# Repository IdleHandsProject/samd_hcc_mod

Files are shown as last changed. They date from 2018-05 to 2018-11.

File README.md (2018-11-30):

# SAMD21 HCC Module

Check out the Kickstarter for the HCC Module!

[HCC Mod Kickstarter](https://www.kickstarter.com/projects/idlehandsdev/hcc-mod-ready-to-solder-arduino-module)

An easy to solder Arduino and CircuitPython compatible surface mount module aimed to bridge the gap between using "off the shelf" microcontrollers to creating custom PCBs. 
The module will come with a standard USB enabled Arduino bootloader.

## Arduino IDE Install

Inside of the folder "BOOTLOADER" there is a folder called "IdleHandsDev". Once you download or clone the repo, take the IdleHandsDev folder and place it in the "hardware" folder found within your default Arduino folder. This will allow you to select the HCC Module in the Arduino IDE. You can also use "Arduino/Genuino Zero (Native USB). It will have the same pinout.

## Videos

Kickstarter Vid (https://youtu.be/BM-LiPFgZBc)

Build Vid (https://youtu.be/7S2FcrVHBxY)

## Demo Boards

### Cherry MX Board

Cherry MX Demo (https://youtu.be/bd1iaVNwYvI)

### MOD_BOY - Arduino Gaming Device and Gaming Controller

MOD BOY (https://youtu.be/LRTtZSRfYVY)

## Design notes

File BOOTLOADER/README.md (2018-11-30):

* Transfer "IdleHandsDev" folder into your Arduino/hardware folder to view the "HCC Module" board. Otherwise use either "Arduino Zero (Native USB)" or "Sparkfun SAMD Breakout Board" *

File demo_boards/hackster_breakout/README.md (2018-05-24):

# SAMD21 Bridge Module
An easy to solder Arduino compatible surface mount module aimed to bridge the gap between using "off the shelf" microcontrollers to creating custom PCBs.

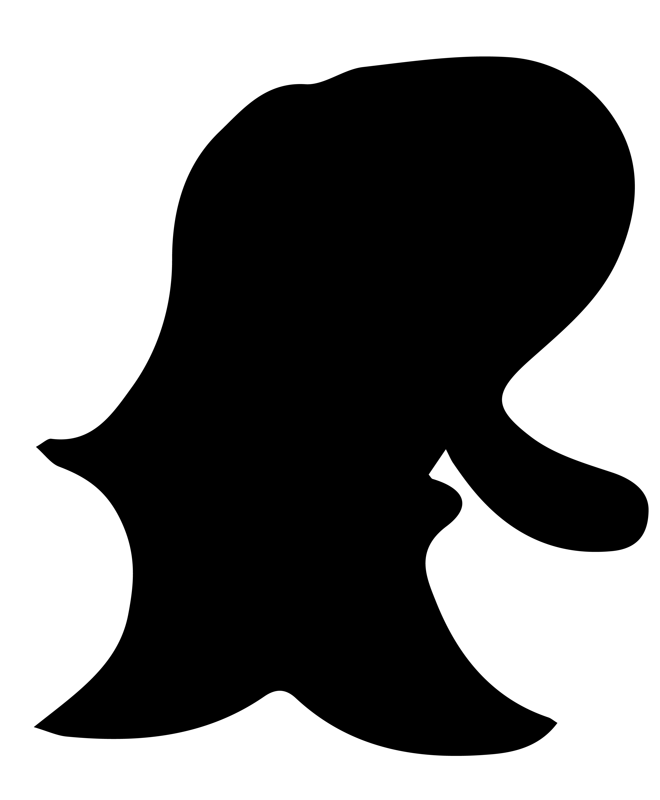
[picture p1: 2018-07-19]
demo_boards/programmer_hcc/images/1600ppi/Asset 3.png

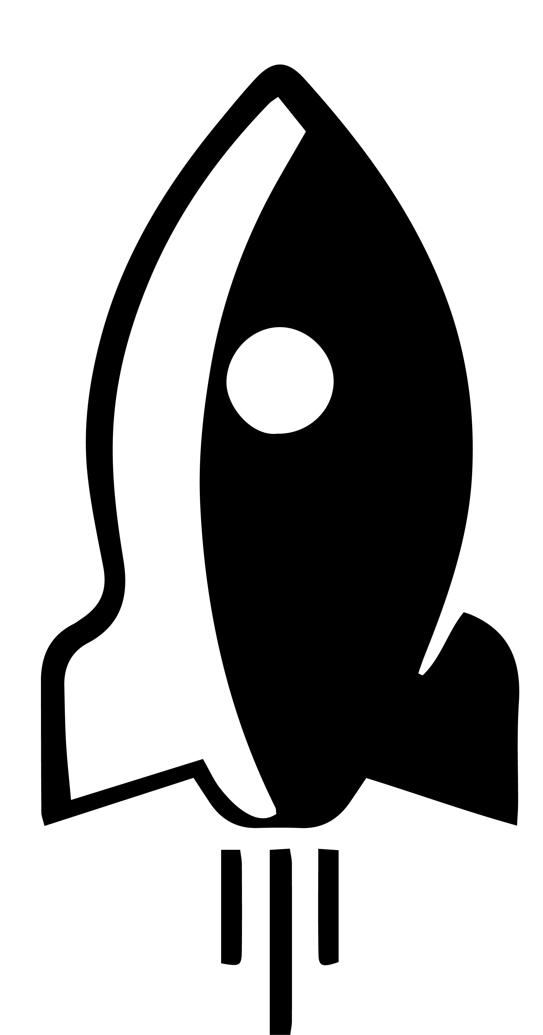
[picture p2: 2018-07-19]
demo_boards/hcc_boy/images/1600ppi/Asset 1.png

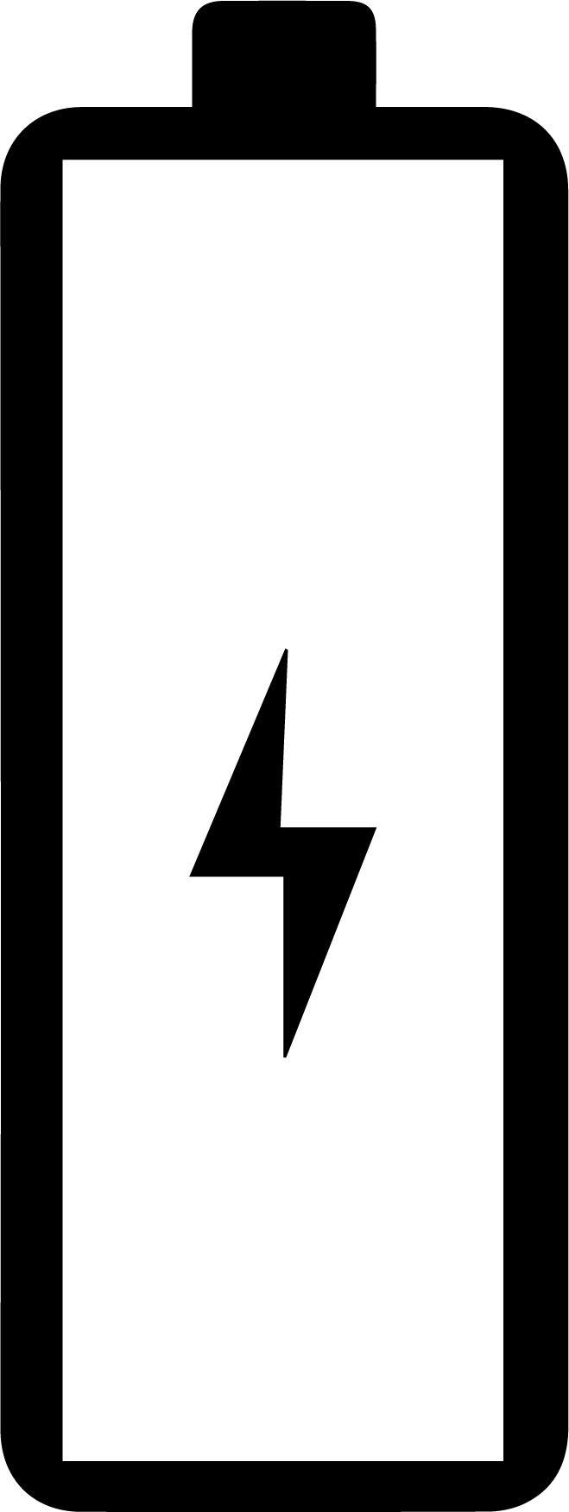
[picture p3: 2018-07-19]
demo_boards/hcc_boy/images/300ppi/Asset 1.png

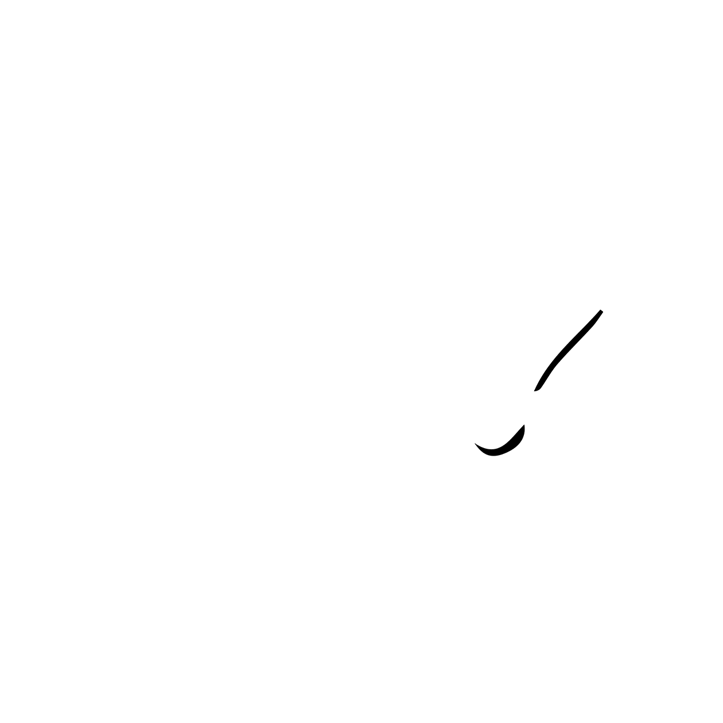
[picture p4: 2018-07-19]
demo_boards/programmer_hcc/images/BOOTCOMMANDER_MASK.png

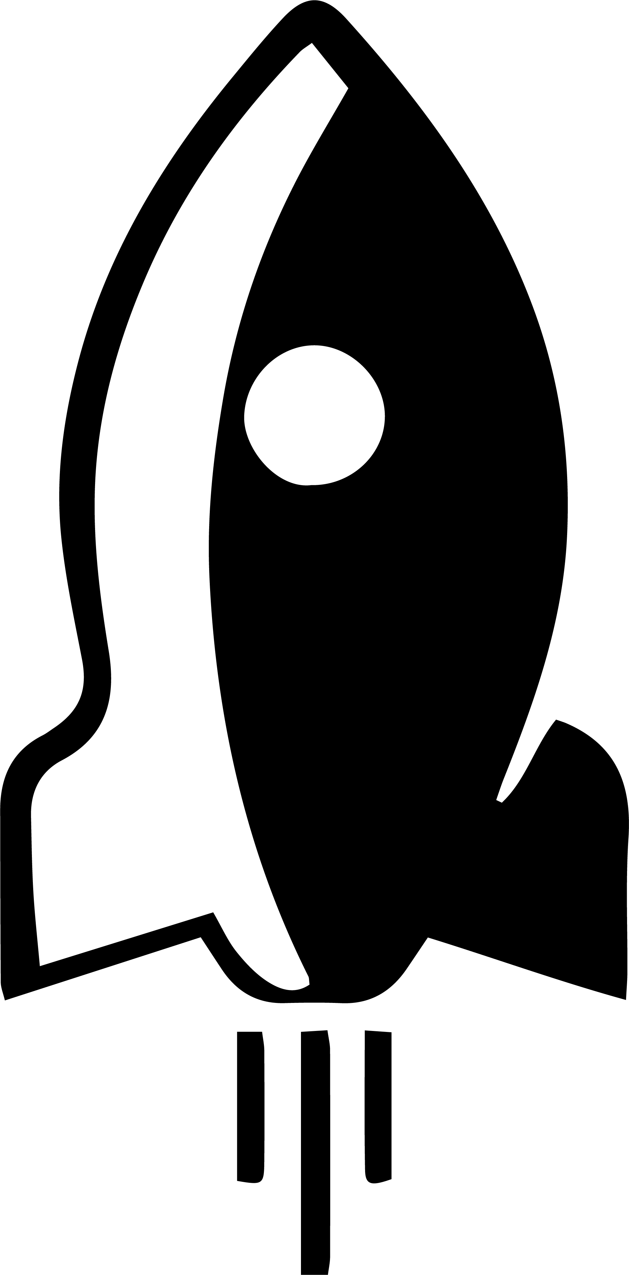
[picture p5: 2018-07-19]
demo_boards/hcc_boy/images/1600ppi/Asset 2.png

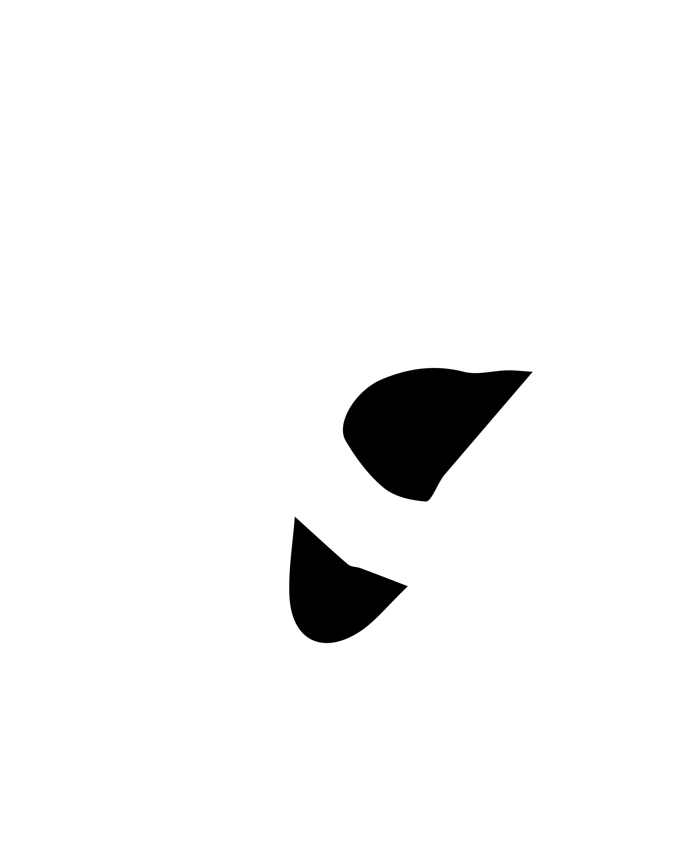
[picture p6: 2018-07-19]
demo_boards/programmer_hcc/images/1600ppi/Asset 1.png

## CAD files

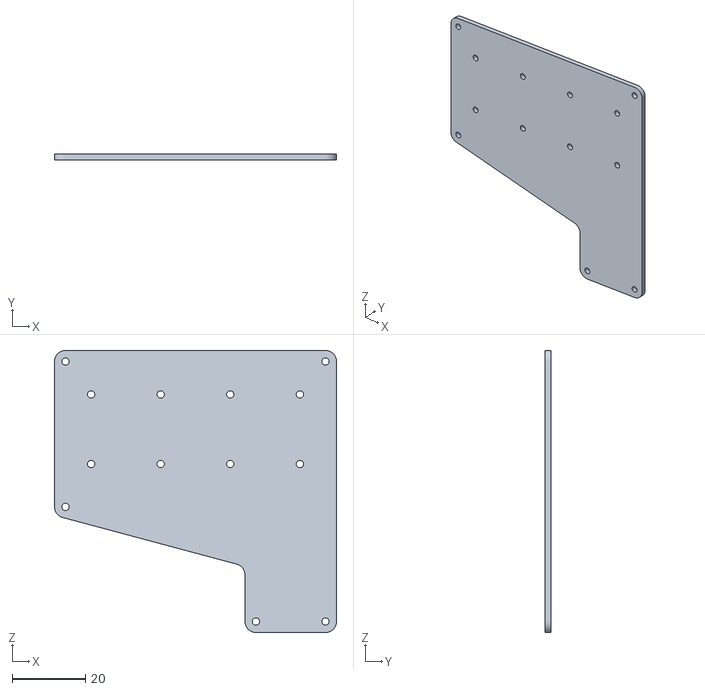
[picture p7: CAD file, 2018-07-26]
demo_boards/Cherry MX Board/pcb/PCB_Body.stl
77.0 x 1.60 x 77.0

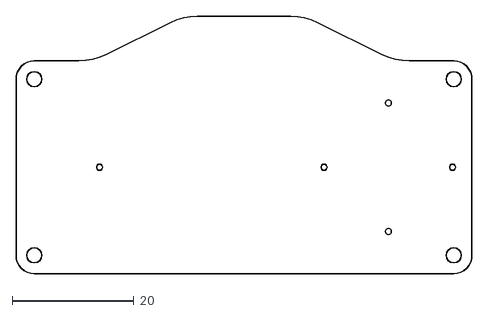
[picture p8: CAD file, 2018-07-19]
demo_boards/hcc_boy/pcb.dxf
75.0 x 42.3

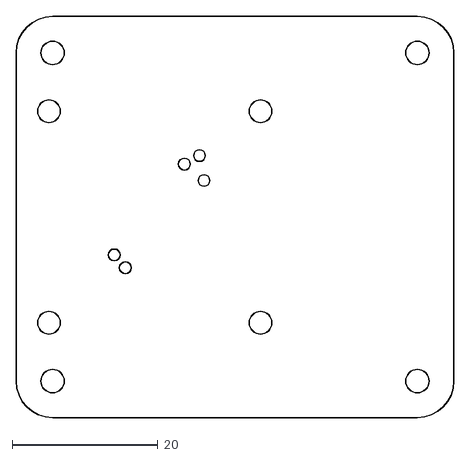
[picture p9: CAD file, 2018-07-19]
demo_boards/programmer_hcc/Board.dxf
60.0 x 55.0

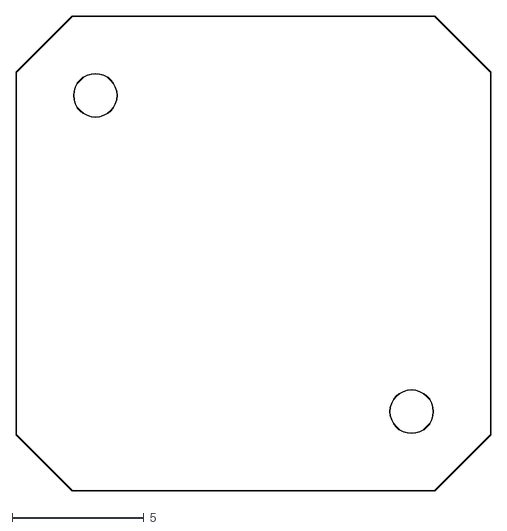
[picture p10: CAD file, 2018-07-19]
demo_boards/hcc_boy/joystick.dxf
18.0 x 18.0

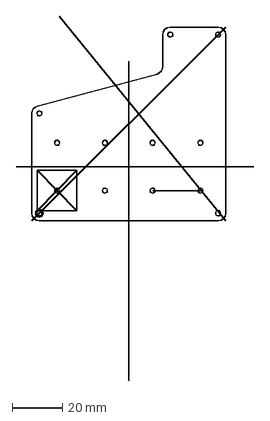
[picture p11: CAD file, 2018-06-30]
demo_boards/Cherry MX Board/pcb/pcb.dxf
94.6 x 144.7 mm

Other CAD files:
demo_boards/hackster_breakout/dxf/Hackster_thumb.dxf
demo_boards/Cherry MX Board/pcb/CherryMX_pcb v2.step
demo_boards/hcc_boy/HCC_PCB.CATPart

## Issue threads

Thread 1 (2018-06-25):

Remove Fuse

hodginsa, 2018-06-25:
Remove Fuse on Board. Not needed as there is no battery charging. (Can be added in line on custom boards)

hodginsa, 2018-07-18:
Gone

Closed 2018-07-18.

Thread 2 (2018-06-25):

Switch Diodes to Single Array

hodginsa, 2018-06-25:
Change the BAT20J diodes to a single diode array for easier assembly and cost(possibly PMEG3005CT).

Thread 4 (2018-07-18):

Change Voltage Regulator

hodginsa, 2018-07-18:
The footprint for the MIC5353 doesn't seem to be good at seating properly. I can see future issues with manufacturing. It looks like there is enough room to fit the well known and tested AP2112K (SOT23-5) - so I will attempt change to that.

hodginsa, 2018-07-26:
Added AP2112K

Closed 2018-07-26.

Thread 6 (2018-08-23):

Parts Lists/BOM

PatchBOTS, 2018-08-23:
Thanks making this available. Would you be able to add a parts list for the components needed for this board?

LouisPi, 2018-09-08:
Navigate to this file - samd_hcc_mod/hcc_g/PCB/hccg.sch and you can read through and pick out the Digikey Part Numbers in there. I have made a Digikey cart which you can find screenshotted here - [](https://drive.google.com/file/d/1XTthXd4_vubhAnmDBuWKl-VHy6x5N6vz/view?usp=sharing), although I have changed some of the components to the most cost effective equivalents in the UK (as Sean is in Canada).

PatchBOTS, 2018-09-10:
Thanks @LouisPi, yes this is very helpful.  Sean also responded to the same question on Kickstarter with this link to a FindChips.com link:   https://www.findchips.com/org/10-open-hardware/list/89833-hcc-module

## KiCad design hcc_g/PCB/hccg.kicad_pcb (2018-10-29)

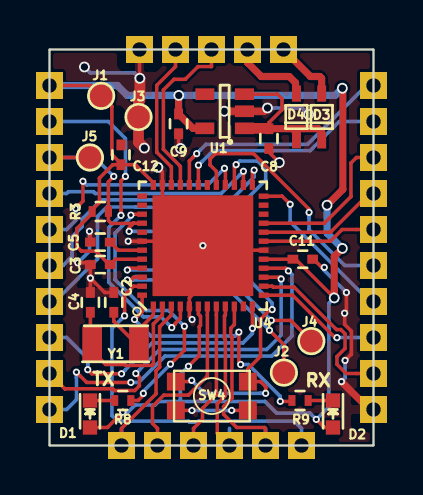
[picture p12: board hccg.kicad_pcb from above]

Board: 2 copper layers, 18.0 x 22.0 mm, 25 parts (0 on the bottom side), 40 nets.

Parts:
C2, C4: 15pF; C_0402
C3, C5, C11, C12: 0.1uF; C_0402
C8, C9: 1uF; C_0402
D1: GLED; LED-0603
D2: YLED; LED-0603
D3, D4: BAT20J; SOD-323
J1, J2, J3, J4, J5: TEST_1P; TESTP_1_5
R3: 10k; R_0402
R8, R9: 1k; R_0402
SW4: SW_PUSH; switch_kmr2
U1: AP2112K-3.3V; SOT-23-5
U2: SAMD21G18; QFN-48-EP-ST_NoVia
U4: SAMD21_MOD; SAMD21G18_MOD
Y1: Crystal_Small; crystal_smd_3.20x1.50mm2

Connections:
+3V3: C3.1, C9.1, C11.1, C12.1, D1.2, D2.2, J1.1, R3.1, U1.5, U2.6, U2.17, U2.36, U2.44, U4.1
+BATT: D3.2, U4.27
A0/DAC: U2.3, U4.11
A1: U2.7, U4.12
A2: U2.8, U4.13
A3: U2.9, U4.14
A4: U2.10, U4.15
A5: U2.47, U4.16
AREF: U2.4, U4.2
CLK: U2.20, U4.23
D3: U2.14, U4.18
D4: U2.13, U4.19
D5: U2.24, U4.20
D6: U2.29, U4.21
D9: U2.12, U4.8
D10: U2.27, U4.7
D11: U2.25, U4.6
D12: U2.28, U4.5
D13: U2.26, U4.4
GND: C2.2, C3.2, C4.2, C5.2, C8.2, C9.2, C11.2, C12.2, J3.1, SW4.2, U1.2, U2.5, U2.18, U2.35, U2.42, U4.17, U4.31
MISO: U2.21, U4.24
MOSI: U2.19, U4.22
unnamed: C2.1, U2.1, Y1.2
unnamed: C4.1, U2.2, Y1.1
unnamed: C5.1, U2.43
unnamed: C8.1, D3.1, D4.1, U1.1, U1.3
unnamed: D1.1, R8.2
unnamed: D2.1, R9.2
RESET: J5.1, R3.2, SW4.1, U2.40, U4.3
RX/D0: U2.16, U4.10
RXLED: R9.1, U2.48
SCL: U2.32, U4.26
SDA: U2.31, U4.25
SWCLK: J4.1, U2.45
SWDIO: J2.1, U2.46
TX/D1: U2.15, U4.9
TXLED: R8.1, U2.39
USB_D+: U2.34, U4.30
USB_D-: U2.33, U4.29
VBUS: D4.2, U4.28

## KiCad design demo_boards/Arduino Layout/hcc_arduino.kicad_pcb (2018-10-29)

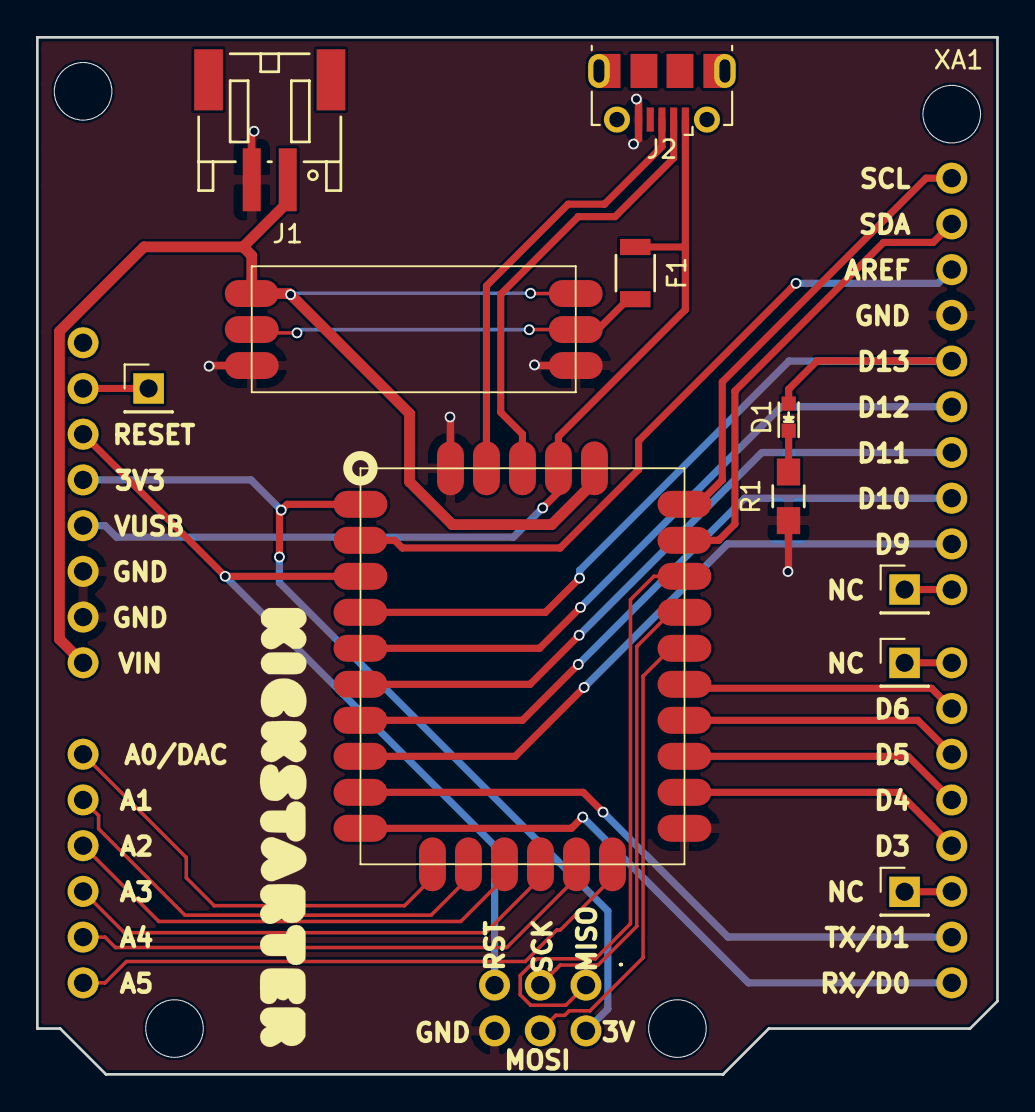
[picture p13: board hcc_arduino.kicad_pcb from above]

Board: 2 copper layers, 53.3 x 57.6 mm, 12 parts (0 on the bottom side), 36 nets.

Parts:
D1: LED; LED-0603
F1: Fuse; R_1206
J1: BATT; Connectors_JST_S2B-PH-SM4-TB
J2: USB_OTG; USB_Micro-B_Molex-105017-0001
J3: D2; Pin_Header_Straight_1x01_Pitch2.54mm
J4: D7; Pin_Header_Straight_1x01_Pitch2.54mm
J5: D8; Pin_Header_Straight_1x01_Pitch2.54mm
J6: IOREF; Pin_Header_Straight_1x01_Pitch2.54mm
R1: 2k; R_0805_HandSoldering
U1: SAMD21_MOD; SAMD_HCC_G_FOOT
U2: charge_mod; LIPO_CHARGE_MOD_FOOTPRINT
XA1: Arduino_M0_Shield; Arduino_HCC

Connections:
+3V3: U1.1, XA1.3V3, XA1.5V2
+BATT: J1.1, U1.27, U2.1, XA1.VIN
A0/DAC: U1.11, XA1.A0
A1: U1.12, XA1.A1
A2: U1.13, XA1.A2
A3: U1.14, XA1.A3
A4: U1.15, XA1.A4
A5: U1.16, XA1.A5
AREF: U1.2, XA1.AREF
CLK: U1.23, XA1.SCK
D3: U1.18, XA1.D3
D4: U1.19, XA1.D4
D5: U1.20, XA1.D5
D6: U1.21, XA1.D6
D9: U1.8, XA1.D9
D10: U1.7, XA1.D10
D11: U1.6, XA1.D11
D12: U1.5, XA1.D12
D13: D1.2, U1.4, XA1.D13
GND: J1.2, J2.5, R1.1, U1.17, U1.31, U2.3, XA1.GND1, XA1.GND2, XA1.GND3, XA1.GND4
MISO: U1.24, XA1.MISO
MOSI: U1.22, XA1.MOSI
unnamed: D1.1, R1.2
unnamed: F1.2, U2.2
unnamed: J2.2, U1.29
unnamed: J2.3, U1.30
unnamed: J3.1, XA1.D2
unnamed: J4.1, XA1.D7
unnamed: J5.1, XA1.D8
unnamed: J6.1, XA1.IORF
RESET: U1.3, XA1.RST1, XA1.RST2
RX/D0: U1.10, XA1.D0
SCL: U1.26, XA1.SCL
SDA: U1.25, XA1.SDA
TX/D1: U1.9, XA1.D1
VBUS: F1.1, J2.1, U1.28, XA1.5V1

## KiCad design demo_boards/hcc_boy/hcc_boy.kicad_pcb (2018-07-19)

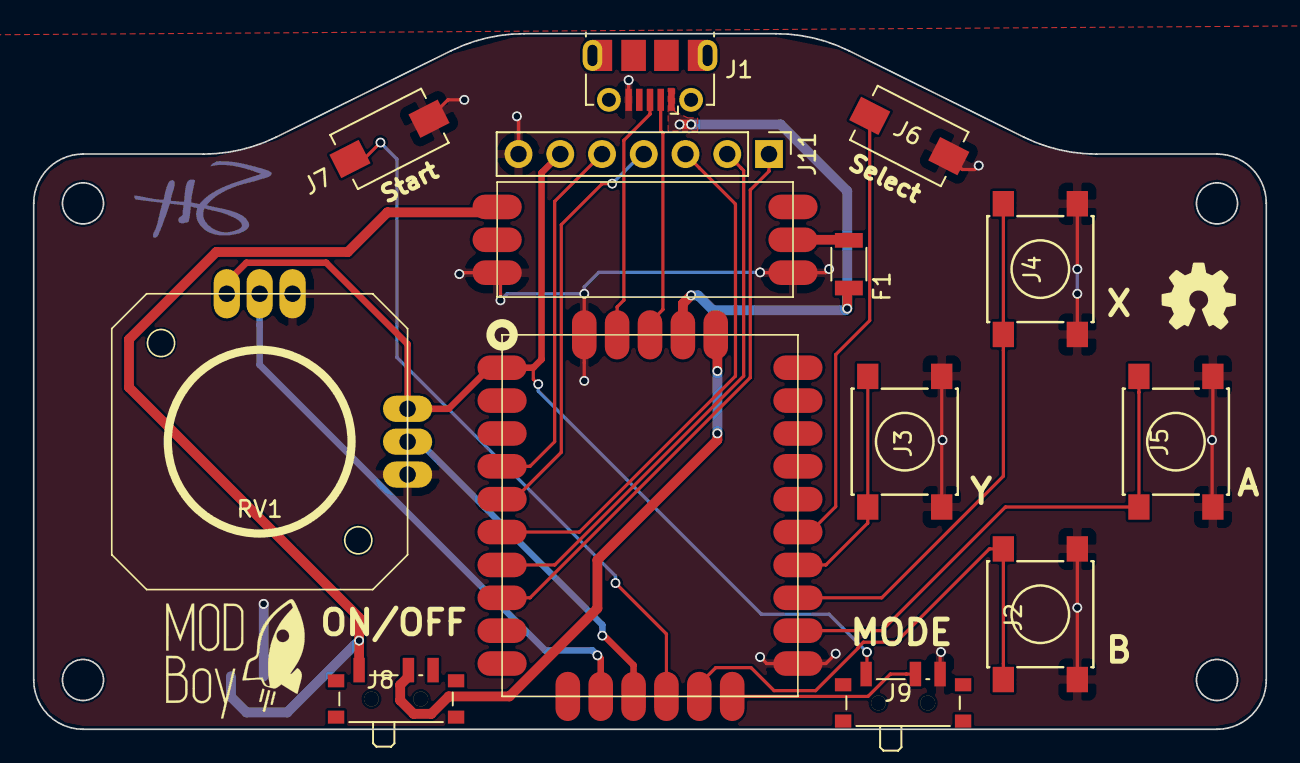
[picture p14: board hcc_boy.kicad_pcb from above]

Board: 2 copper layers, 75.0 x 42.3 mm, 15 parts (1 on the bottom side), 22 nets.

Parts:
BT1: Battery_Cell; Connectors_JST_S2B-PH-SM4-TB
F1: Fuse; R_1206
J1: USB_OTG; USB_Micro-B_Molex-105017-0001
J2: A; SW_SPST_PTS645
J3: B; SW_SPST_PTS645
J4: X; SW_SPST_PTS645
J5: Y; SW_SPST_PTS645
J6: Start; SW_SPST_EVQPE1
J7: Select; SW_SPST_EVQPE1
J8: PWR; SW_SPDT_PCM12
J9: Selector; SW_SPDT_PCM12
J11: OLED; Pin_Header_Straight_1x07_Pitch2.54mm
RV1: JOYSTICK; JOYSTICK_MINI_2AXIS
U1: charge_mod; LIPO_CHARGE_MOD_FOOTPRINT
U4: SAMD21_MOD; SAMD_HCC_G_FOOT

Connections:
+3V3: J9.1, J11.6, RV1.3, RV1.6, U4.1
+BATT: BT1.1, J8.1, U1.1
A1: RV1.5, U4.12
A2: RV1.2, U4.13
A3: J7.1, U4.14
A4: J2.1, U4.15
A5: J9.2, U4.16
D3: J5.1, U4.18
D4: J4.1, U4.19
D5: J3.1, U4.20
D6: J6.1, U4.21
D9: J11.1, U4.8
D10: J11.2, U4.7
D11: J11.3, U4.6
D12: J11.4, U4.5
D13: J11.5, U4.4
GND: BT1.2, J1.5, J2.2, J3.2, J4.2, J5.2, J6.2, J7.2, J9.3, J11.7, RV1.1, RV1.4, U1.3, U4.17, U4.31
unnamed: F1.2, U1.2
unnamed: J1.2, U4.29
unnamed: J1.3, U4.30
unnamed: J8.2, U4.27
VBUS: F1.1, J1.1, U4.28

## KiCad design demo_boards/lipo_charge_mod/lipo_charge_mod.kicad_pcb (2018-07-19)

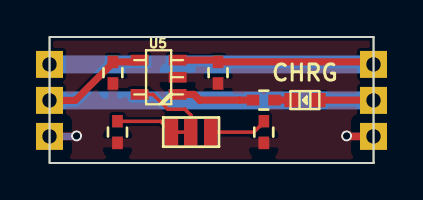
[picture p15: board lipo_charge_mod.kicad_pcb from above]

Board: 2 copper layers, 18.0 x 7.0 mm, 9 parts (0 on the bottom side), 7 nets.

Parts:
C7, C10: 4.7uF; C_0402_Hand
D6: CHRG; Led_0603
J1: GS3; 3WAY_JUMPER_SMD
J2: Conn_01x06; LIPO_CHARGE_MOD
R1: 0; R_0402_Hand
R5: 33k; R_0402_Hand
R14: 1K; R_0402_Hand
U5: MCP73831T; sot23-5

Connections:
GND: C7.2, C10.2, J2.3, J2.6, R1.1, R5.1, U5.2
unnamed: D6.1, R14.2
unnamed: J1.1, R1.2
unnamed: J1.2, J1.3, R5.2, U5.5
unnamed: R14.1, U5.1
VBATT: C10.1, J2.1, J2.4, U5.3
VCC: C7.1, D6.2, J2.2, J2.5, U5.4

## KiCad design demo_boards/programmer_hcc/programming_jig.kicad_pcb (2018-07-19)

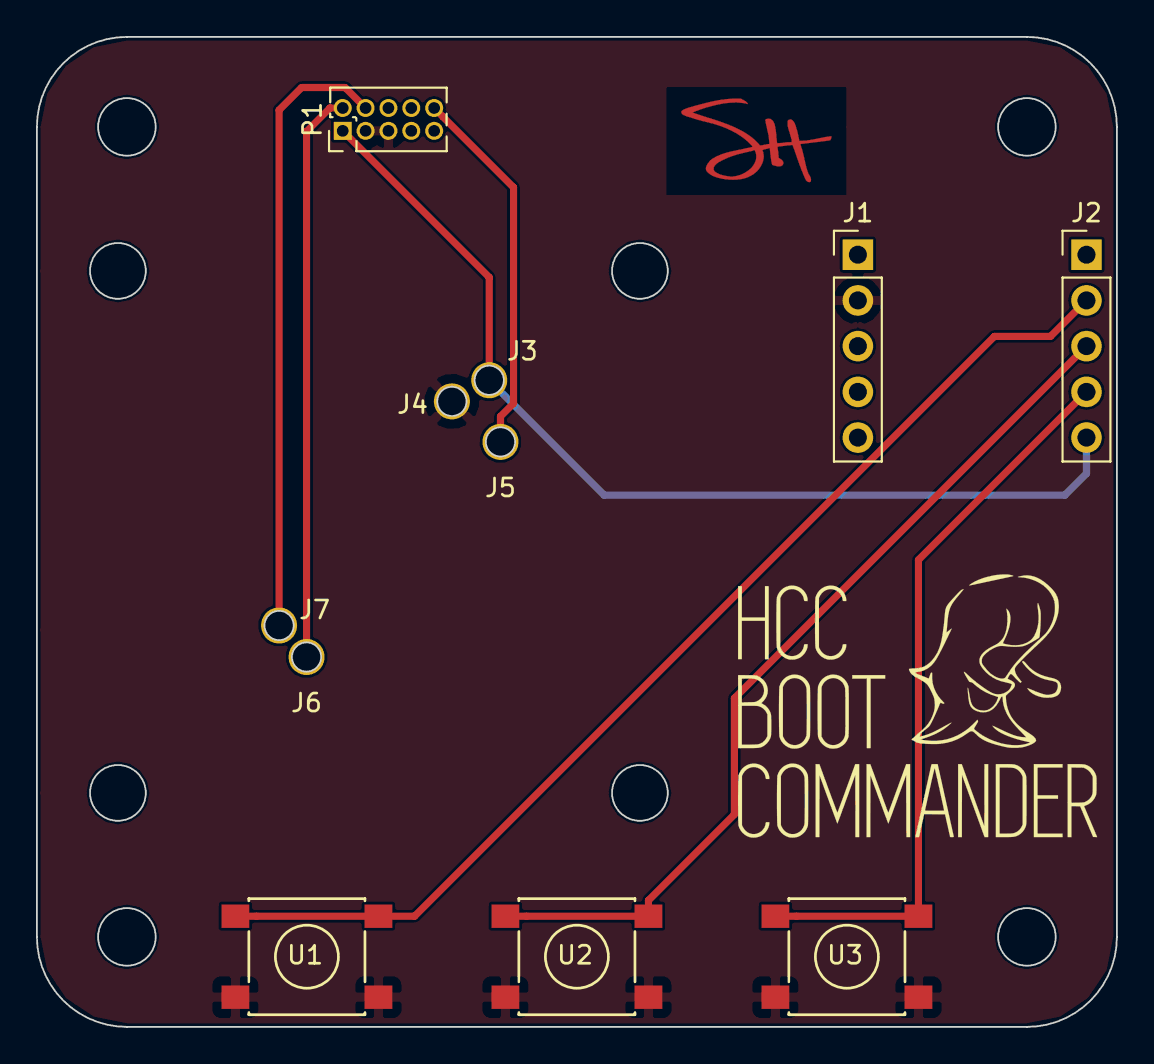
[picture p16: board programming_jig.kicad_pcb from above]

Board: 2 copper layers, 60.0 x 55.0 mm, 11 parts (0 on the bottom side), 8 nets.

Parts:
J1: Trinket_Left; Pin_Header_Straight_1x05_Pitch2.54mm
J2: Trinket_Right; Pin_Header_Straight_1x05_Pitch2.54mm
J3: 3V3; POGO_PIN
J4: GND; POGO_PIN
J5: RST; POGO_PIN
J6: SWDIO; POGO_PIN
J7: SWCLK; POGO_PIN
P1: DBG_CONN; Pin_Header_Straight_2x05_Pitch1.27mm
U1: SW1; SW_SPST_PTS645
U2: SW2; SW_SPST_PTS645
U3: SW3; SW_SPST_PTS645

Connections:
0: J2.2, U1.1
1: J2.3, U2.1
2: J2.4, U3.1
+3V3: J2.5, J3.1, P1.1
GND: J1.2, J4.1, P1.3, P1.5, U1.2, U2.2, U3.2
RST: J5.1, P1.10
SWCLK: J7.1, P1.4
SWDIO: J6.1, P1.2

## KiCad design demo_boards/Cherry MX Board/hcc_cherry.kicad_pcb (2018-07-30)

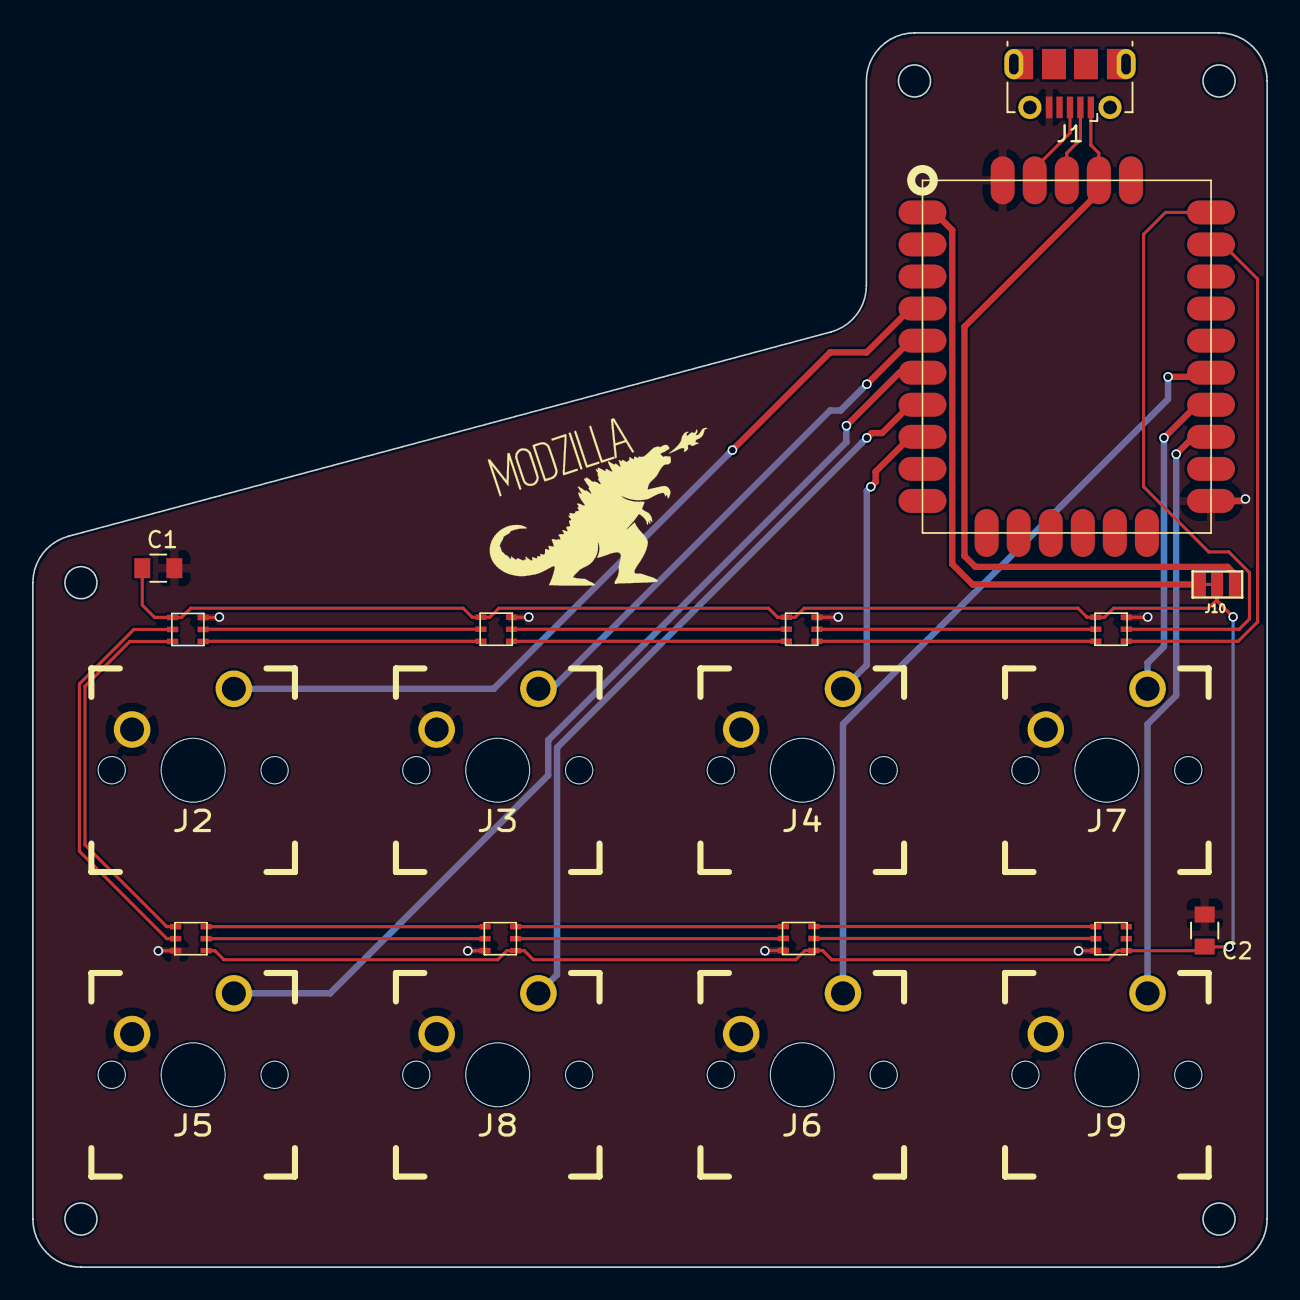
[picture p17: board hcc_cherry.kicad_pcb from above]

Board: 2 copper layers, 77.0 x 77.0 mm, 21 parts (0 on the bottom side), 29 nets.

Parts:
C1, C2: 1uF; C_0805
J1: USB_OTG; USB_Micro-B_Molex-105017-0001
J2: SW1; CHERRY_PCB_100H
J3: SW2; CHERRY_PCB_100H
J4: SW3; CHERRY_PCB_100H
J5: SW4; CHERRY_PCB_100H
J6: SW5; CHERRY_PCB_100H
J7: SW6; CHERRY_PCB_100H
J8: SW7; CHERRY_PCB_100H
J9: SW8; CHERRY_PCB_100H
J10: GS3; 3WAY_JUMPER_SMD
U1, U2, U3, U5, U6, U7, U8, U9: APA102; APA102-2020_AFSTYLE
U4: SAMD21_MOD; SAMD_HCC_G_FOOT

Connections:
+3V3: C1.1, C2.1, J10.2, J10.3, U1.1, U2.1, U3.1, U4.1, U5.1, U6.1, U7.1, U8.1, U9.1
CKI: U1.5, U4.26
D4: J9.1, U4.19
D5: J7.1, U4.20
D6: J6.1, U4.21
D9: J4.1, U4.8
D10: J8.1, U4.7
D11: J5.1, U4.6
D12: J3.1, U4.5
D13: J2.1, U4.4
GND: C1.2, C2.2, J1.5, J2.2, J3.2, J4.2, J5.2, J6.2, J7.2, J8.2, J9.2, U1.6, U2.6, U3.6, U4.17, U4.31, U5.6, U6.6, U7.6, U8.6, U9.6
unnamed: J1.2, U4.29
unnamed: J1.3, U4.30
unnamed: U1.2, U2.5
unnamed: U1.3, U2.4
unnamed: U2.2, U3.5
unnamed: U2.3, U3.4
unnamed: U3.2, U5.5
unnamed: U3.3, U5.4
unnamed: U5.2, U6.5
unnamed: U5.3, U6.4
unnamed: U6.2, U7.5
unnamed: U6.3, U7.4
unnamed: U7.2, U8.5
unnamed: U7.3, U8.4
unnamed: U8.2, U9.5
unnamed: U8.3, U9.4
SDI: U1.4, U4.25
VBUS: J1.1, J10.1, U4.28

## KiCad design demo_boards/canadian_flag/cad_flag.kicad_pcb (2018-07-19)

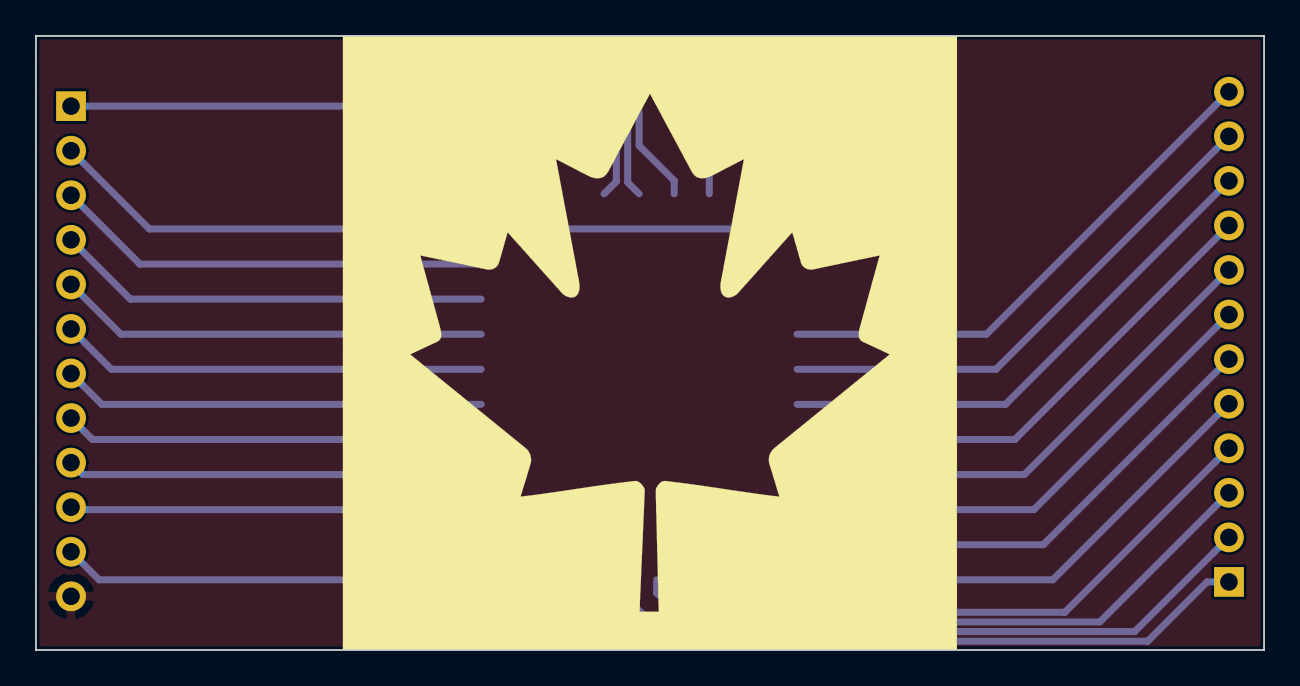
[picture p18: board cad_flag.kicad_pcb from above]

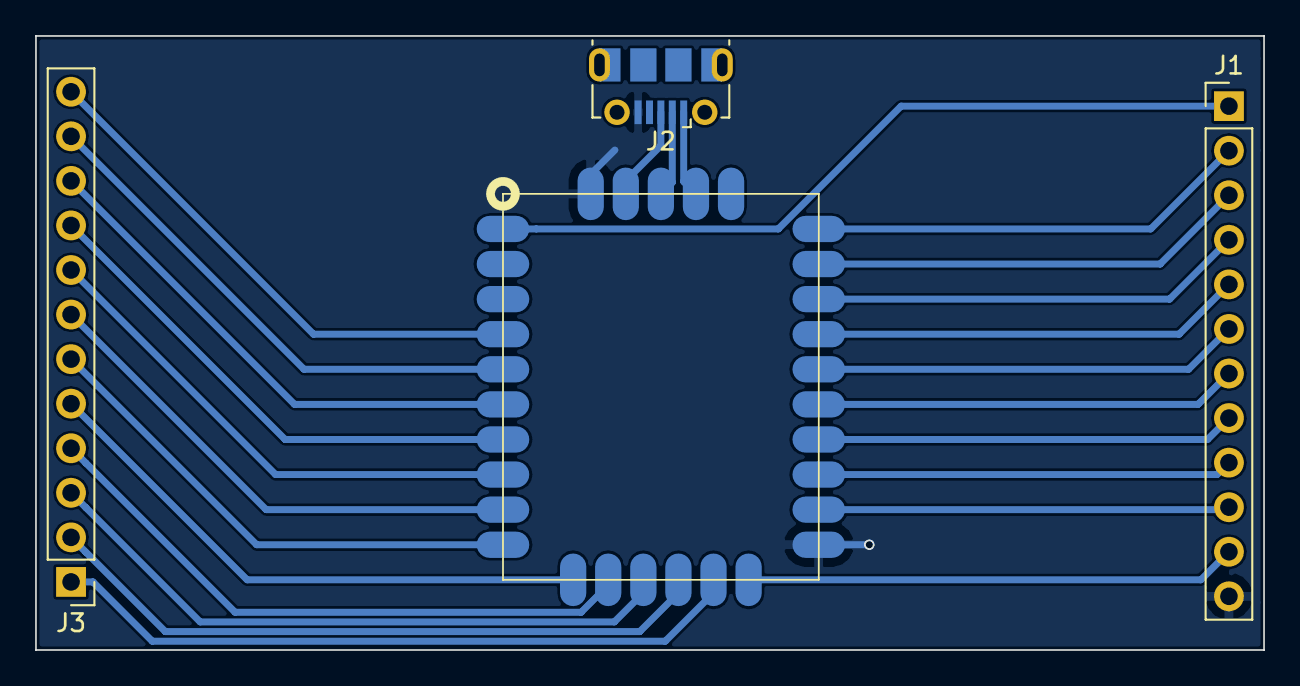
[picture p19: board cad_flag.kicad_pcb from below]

Board: 2 copper layers, 70.0 x 35.0 mm, 4 parts (4 on the bottom side), 27 nets.

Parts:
J1, J3: Conn_01x12; Pin_Header_Straight_1x12_Pitch2.54mm
J2: USB_OTG; USB_Micro-B_Molex-105017-0001
U1: SAMD21_MOD; SAMD_HCC_G_FOOT

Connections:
+3V3: J1.1, U1.1
A0/DAC: J3.5, U1.11
A1: J3.4, U1.12
A2: J3.3, U1.13
A3: J3.2, U1.14
A4: J3.1, U1.15
A5: J1.11, U1.16
CLK: J1.5, U1.23
D3: J1.10, U1.18
D4: J1.9, U1.19
D5: J1.8, U1.20
D6: J1.7, U1.21
D9: J3.8, U1.8
D10: J3.9, U1.7
D11: J3.10, U1.6
D12: J3.11, U1.5
D13: J3.12, U1.4
GND: J1.12, J2.5, U1.17, U1.31
MISO: J1.4, U1.24
MOSI: J1.6, U1.22
unnamed: J2.1, U1.28
unnamed: J2.2, U1.29
unnamed: J2.3, U1.30
RX/D0: J3.6, U1.10
SCL: J1.2, U1.26
SDA: J1.3, U1.25
TX/D1: J3.7, U1.9

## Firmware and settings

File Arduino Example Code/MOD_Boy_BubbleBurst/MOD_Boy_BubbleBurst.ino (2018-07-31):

/*

Bubble Burst MOD_Boy Example GAME!

The MOD_Boy is Open Source Hardware that uses the HCC Module. 
Check out the Kickstarter for the HCC Module: http://bit.ly/hccmodule
GITHUB for all of the HCC Module stuff(and demo boards like this one): https://github.com/IdleHandsProject/samd_hcc_mod

For more information on the MOD_Boy and the HCC Module check out https://Youtube.com/SeanHodginsFilms

I go through this code in a video, check it out here: https://youtu.be/LRTtZSRfYVY

*/

#include <math.h>

#include <Arduino.h>
#include <U8g2lib.h>

#ifdef U8X8_HAVE_HW_SPI
#include <SPI.h>
#endif
#ifdef U8X8_HAVE_HW_I2C
#include <Wire.h>
#endif

//#define Serial SerialUSB

//LOGO

#define logo_width 8
#define logo_height 48

////////////MOD BOY LOGO

static unsigned char MODBoylogo_bits[] = {0x00, 0x00, 0x00, 0x00, 0x00, 0x00, 0x00, 0x00, 0x00, 0x00, 0x00, 0x00, 0x00, 0x00, 0x00, 0x00,
                                          0x00, 0x00, 0x00, 0x00, 0x00, 0x00, 0x00, 0x00, 0x00, 0x00, 0x00, 0x00, 0x00, 0x00, 0x1C, 0x00,
                                          0x00, 0x00, 0x0C, 0x1F, 0x00, 0x00, 0x36, 0x00, 0x0C, 0x02, 0x3F, 0x1F, 0x80, 0x00, 0x66, 0x00,
                                          0x0C, 0x02, 0x61, 0x90, 0x40, 0x01, 0x87, 0x00, 0x0C, 0x06, 0x40, 0x90, 0x60, 0x03, 0x0F, 0x00,
                                          0x0E, 0x06, 0x40, 0x90, 0x60, 0x06, 0x1F, 0x00, 0x0A, 0x0E, 0x40, 0x90, 0x60, 0x0C, 0x3F, 0x80,
                                          0x0B, 0x0A, 0x40, 0x90, 0x60, 0x08, 0x3F, 0x80, 0x09, 0x0A, 0x40, 0x90, 0x60, 0x18, 0x7F, 0x80,
                                          0x09, 0x12, 0x40, 0x90, 0x60, 0x30, 0xFF, 0xC0, 0x09, 0x92, 0x40, 0x90, 0x60, 0x20, 0xFF, 0xC0,
                                          0x08, 0xB2, 0x40, 0x90, 0x60, 0x61, 0xBF, 0xC0, 0x08, 0xA2, 0x40, 0x90, 0x60, 0x41, 0x0F, 0xC0,
                                          0x08, 0x62, 0x40, 0x90, 0x60, 0xC2, 0x0F, 0xC0, 0x08, 0x62, 0x40, 0x90, 0x60, 0xC2, 0x0F, 0xC0,
                                          0x08, 0x42, 0x40, 0x90, 0x60, 0x83, 0x0F, 0xC0, 0x08, 0x02, 0x40, 0x90, 0x60, 0x87, 0xFF, 0xC0,
                                          0x08, 0x02, 0x61, 0x90, 0x40, 0x87, 0xFF, 0xC0, 0x08, 0x02, 0x33, 0x11, 0x80, 0x87, 0xFF, 0xC0,
                                          0x08, 0x02, 0x1E, 0x1F, 0x01, 0x8F, 0xFF, 0x80, 0x00, 0x00, 0x00, 0x00, 0x01, 0x8F, 0xFF, 0x80,
                                          0x00, 0x00, 0x00, 0x00, 0x01, 0x0F, 0xFF, 0x80, 0x0F, 0xC0, 0x00, 0x00, 0x07, 0x0F, 0xFF, 0x00,
                                          0x08, 0x20, 0x00, 0x00, 0x0E, 0x0F, 0xFF, 0x00, 0x08, 0x30, 0x00, 0x00, 0x18, 0x0F, 0xFE, 0x00,
                                          0x08, 0x10, 0x00, 0x00, 0x18, 0x0F, 0xFE, 0x00, 0x08, 0x10, 0x60, 0x00, 0x10, 0x0F, 0xFC, 0x00,
                                          0x08, 0x20, 0xF9, 0x82, 0x10, 0x0F, 0xF9, 0x00, 0x0F, 0xE1, 0x0C, 0x82, 0x30, 0x0F, 0xFF, 0x80,
                                          0x0F, 0xE3, 0x04, 0x86, 0x30, 0x0F, 0xFF, 0x80, 0x08, 0x13, 0x04, 0x86, 0x3F, 0xCF, 0xFF, 0x80,
                                          0x08, 0x1B, 0x04, 0xC4, 0x00, 0x4F, 0xFF, 0x80, 0x08, 0x0B, 0x04, 0x44, 0x00, 0x27, 0xFF, 0x00,
                                          0x08, 0x0B, 0x04, 0x4C, 0x00, 0x1F, 0x3F, 0x00, 0x08, 0x0B, 0x04, 0x6C, 0x00, 0x00, 0x0F, 0x00,
                                          0x08, 0x0B, 0x04, 0x68, 0x00, 0x48, 0x07, 0x00, 0x08, 0x0B, 0x04, 0x28, 0x00, 0x5A, 0x00, 0x00,
                                          0x08, 0x19, 0x04, 0x38, 0x00, 0x52, 0x00, 0x00, 0x08, 0x31, 0x88, 0x10, 0x00, 0xD4, 0x00, 0x00,
                                          0x0F, 0xE0, 0xF0, 0x10, 0x00, 0x14, 0x00, 0x00, 0x00, 0x00, 0x00, 0x10, 0x00, 0x34, 0x00, 0x00,
                                          0x00, 0x00, 0x00, 0x30, 0x00, 0x20, 0x00, 0x00, 0x00, 0x00, 0x00, 0x30, 0x00, 0x20, 0x00, 0x00,
                                          0x00, 0x00, 0x00, 0x20, 0x00, 0x00, 0x00, 0x00, 0x00, 0x00, 0x00, 0x20, 0x00, 0x00, 0x00, 0x00
                                         };

//MOD_boy Button Declarations

#define START 6
#define SELECT 17
#define A 18
#define B 5
#define X 4
#define Y 3

#define JOYX 16
#define JOYY 15

#define MODE 19

#define playAREAX  512
#define playAREAY  512

#define OLEDX  64
#define OLEDY  48

int XN = 0; // Neutral Joystick postition.
int YN = 0;

U8G2_SSD1306_64X48_ER_F_4W_SW_SPI oled(U8G2_R0, 13, 12, 9, 10, 11);  //(CLK, DATA, CS, DC, RESET)

//Initial Character Settings

int charR = 2;   //Size of the Character
int charX = 128;     //Character location X
int charY = 128;     //Character location Y
float charACCX = 0;   //Character Momentum X
float charACCY = 0;   //Character Momentum Y
int charMODE = 0;   //Character Mode (For powerups);
int charSCORE = 0;

//Game Settings

int difficulty = 0; //Difficult 0 = Easy, 1 = Pro, 2 = Insane
int contrast = 50;
int npcCOUNT = 10;
int gameRUN = 0;
int gamePAUSE = 0;
int menuSELECT = 1;

#define enemyCOUNT 40
//int enemyCOUNT = 40;
int enemySTAT[enemyCOUNT][5]; //enemy location and stats

int JOYXPOS = 0;
int JOYYPOS = 0;

int spriteCOUNT = 10;

#define particleCOUNT 500
int particle[particleCOUNT][3];

float friction = 0.05;
int eatPART = 0;

void setup(void) {
  oled.setFont(u8g2_font_helvB08_tr);

  SerialUSB.begin(115200);
  SerialUSB.println("MOD_BOY!");
  SerialUSB.println("LOADING BubbleBurst!");

  //Controller Setup
  pinMode (START, INPUT_PULLUP);
  pinMode (SELECT, INPUT_PULLUP);
  pinMode (A, INPUT_PULLUP);
  pinMode (B, INPUT_PULLUP);
  pinMode (X, INPUT_PULLUP);
  pinMode (Y, INPUT_PULLUP);
  pinMode (JOYX, INPUT);
  pinMode (JOYY, INPUT);

  XN = analogRead(JOYX);
  YN = analogRead(JOYY);


  //RANDOMLY PLACE PARTICLES X AND Y
  particle[0][0] = 130;
  particle[0][1] = 125;
  randomSeed(analogRead(A0));
  for (int i = 1; i < particleCOUNT; i++) {
    particle[i][0] = random(playAREAX);
    particle[i][1] = random(playAREAY);
    particle[i][2] = 1; //ALIVE
  }
  for (int k = 0; k < enemyCOUNT; k++) {
    enemySTAT[k][2] = random(10);  //RADIUS
    enemySTAT[k][0] = random(playAREAX - enemySTAT[k][2]); //X POSITION
    enemySTAT[k][1] = random(playAREAY - enemySTAT[k][2]); //Y POSITION
    enemySTAT[k][3] = 1; //ALIVE STATUS 1:ALIVE 0:DEAD
    enemySTAT[k][4] = 0; // TIME SINCE DEAD
  }
  oled.begin();
  oled.setFlipMode(0);

  analogReadResolution(10);

  attachInterrupt(START, Start, FALLING);
  oled.firstPage();
  do {
    drawLogo();
  } while ( oled.nextPage() );

  delay(2000);
  int lastSELECT = 0;
  //INITIAL GAME MENU
  while (gameRUN == 0) {
    JOYYPOS = analogRead(JOYY);
    SerialUSB.println(JOYYPOS);
    if (JOYYPOS > 900) {
      if (menuSELECT == 2) {
        menuSELECT = 1;
      }
    }
    if (JOYYPOS < 100) {
      if (menuSELECT == 1) {
        menuSELECT = 2;
      }
    }
    oled.firstPage();
    do {
      //oled.userInterfaceSelectionList("BubbleBurst!", menuSELECT, "Start\nSettings");
      oled.drawStr(15, 15, "Bubble");
      oled.drawStr(17, 30, "Burst!");
    } while ( oled.nextPage() );

    //delay(100);
  }
  detachInterrupt(START);

  //while (1);

}

void loop(void) {
  while (gamePAUSE == 0) {
    oled.firstPage();
    do {
      gamePLAY();
    } while ( oled.nextPage() );
  }

}


void gamePLAY() {
  int moveX = analogRead(JOYX);// - XN;
  int moveY = analogRead(JOYY);// - YN;
  moveX = map(moveX, 0, 1023, -500, 500);
  moveY = map(moveY, 0, 1023, -500, 500);
  float mX = float(moveX) / float(1000);
  float mY = float(moveY) / float(1000);

  charACCX = charACCX + mX;
  charACCY = charACCY + mY;
  if (charACCX < 0.1) {
    charACCX = charACCX + friction;
  }
  if (charACCX > 0.1) {
    charACCX = charACCX - friction;
  }
  if (charACCY < 0.1) {
    charACCY = charACCY + friction;
  }
  if (charACCY > 0.1) {
    charACCY = charACCY - friction;
  }

  charACCY = constrain(charACCY, -2, 2);
  charACCX = constrain(charACCX, -2, 2);

  charX = charX + charACCX;
  charY = charY + charACCY;
  charY = constrain(charY, 0, playAREAY);
  charX = constrain(charX, 0, playAREAX);

  //  SerialUSB.print(charX);
  //  SerialUSB.print(",");
  //  SerialUSB.println(charY);
  //  SerialUSB.println(random(-1, 2));

  int displayBOXX = charX + 32;
  int displayBOXY = charY + 24;
  if (charR > 40){
    youWIN();
  }
  oled.drawCircle(32, 24, charR, U8G2_DRAW_ALL);

  //  int pCOUNT = 0;
  //  int pDISP[particleCOUNT];

  for (int j = 0; j < enemyCOUNT; j++) {
    if (enemySTAT[j][3] == 1) {
      if (enemySTAT[j][0] < displayBOXX + 20 && enemySTAT[j][0] > (displayBOXX - OLEDX - 20)) {
        if (enemySTAT[j][1] < displayBOXY + 20 && enemySTAT[j][1] > (displayBOXY - OLEDY - 20)) {
          //          int eX = abs(enemySTAT[j][0] - (charX + (OLEDX / 2)));
          //          int eY = abs(enemySTAT[j][1] - (charY + (OLEDY / 2)));
          int eX = ((charX + (OLEDX / 2)) - enemySTAT[j][0]);
          int eY = ((charY + (OLEDY / 2)) - enemySTAT[j][1]);
          oled.drawCircle(eX, eY, enemySTAT[j][2], U8G2_DRAW_ALL);
//          SerialUSB.print(eX);
//          SerialUSB.print(",");
//          SerialUSB.println(eY);
          int touch = checkCONTACT(j, enemySTAT[j][0], enemySTAT[j][1], enemySTAT[j][2]);
          if (touch == 1) {
            if (enemySTAT[j][2] > charR) {
              deadANIMATION();
            }
            if (enemySTAT[j][2] < charR) {
              charR++;
              enemyDEAD(j);
            }
          }
        }
      }
    }
    if (enemySTAT[j][3] == 0) {
      int checkTIME = millis();
      if ((checkTIME - enemySTAT[j][4]) > 5000) {
        enemySTAT[j][0] = random(playAREAX);
        enemySTAT[j][1] = random(playAREAY);
        enemySTAT[j][2] = random(10);
        enemySTAT[j][3] = 1;
        enemySTAT[j][4] = 0;
      }
    }

  }


  for (int i = 0; i < particleCOUNT; i++) {
    if (particle[i][2] == 1) {
      if (particle[i][0] < displayBOXX && particle[i][0] > (displayBOXX - OLEDX)) {
        if (particle[i][1] < displayBOXY && particle[i][1] > (displayBOXY - OLEDY)) {
          int pX = ((charX + (OLEDX / 2)) - particle[i][0]);
          int pY = ((charY + (OLEDY / 2)) - particle[i][1]);
          oled.drawPixel(pX, pY);
          int eat = checkPCONTACT(i, particle[i][0], particle[i][1]);
          if (eat == 1) {
            eatPART ++;
            particle[i][2] = 0;
          }

          int selection = random(100);
          if ((selection % 5) == 0) {
            particle[i][0] += random(-1, 2);
            particle[i][1] += random(-1, 2);
          }

        }
      }
    }
  }
  if (eatPART >= 10) {
    charR++;
    eatPART = 0;
  }

}


void enemyDEAD(int enemyNUM) {
  enemySTAT[enemyNUM][3] = 0;
  enemySTAT[enemyNUM][4] = millis();
}

void deadANIMATION() {
  int sizeR = charR;
  while (sizeR <50){
  oled.firstPage();
  do {
    oled.drawCircle(32, 24, sizeR, U8G2_DRAW_ALL);
    sizeR++;
    
  } while ( oled.nextPage() );
  }
  oled.firstPage();
  do {
    oled.drawStr(15, 15, "Game");
      oled.drawStr(17, 30, "Over.");
  } while ( oled.nextPage() );
  while(1);
}

void youWIN() {
  oled.firstPage();
  do {
    oled.drawStr(15, 15, "You've");
      oled.drawStr(16, 30, "Eaten");
      oled.drawStr(8, 45, "Everything!");
  } while ( oled.nextPage() );
  while(1);
}

int checkCONTACT(int spriteNUM, int spriteX, int spriteY, int spriteR) {
  int contact = 0;
  int xDIST = abs(spriteX - charX);
  int yDIST = abs(spriteY - charY);
  double centerDIST = sqrt((xDIST * xDIST) + (yDIST * yDIST));
  int combineR = charR + spriteR;
  if (combineR > centerDIST) {
    contact = 1;
  }
  return contact;
}

int checkPCONTACT(int spriteNUM, int spriteX, int spriteY) {
  int contact = 0;
  int xDIST = abs(spriteX - charX);
  int yDIST = abs(spriteY - charY);
  double centerDIST = sqrt((xDIST * xDIST) + (yDIST * yDIST));
  if (charR > centerDIST) {
    contact = 1;
  }
  return contact;
}
void Pause() {
}

void Start() {
  gameRUN = 1;
  int startState = digitalRead(START);
  while (startState == 0) {
    startState = digitalRead(START);
  }
}

void drawLogo(void)
{
  uint8_t mdy = 0;
  if ( oled.getDisplayHeight() < 59 )
    mdy = 5;
  oled.drawBitmap(0, 0, logo_width, logo_height, MODBoylogo_bits);
}

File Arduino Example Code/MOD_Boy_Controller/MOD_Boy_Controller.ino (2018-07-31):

#include <Keyboard.h>
#include <SPI.h>


// Special keycodes (e.g. shift, arrows, etc.) are documented here:
// https://www.arduino.cc/en/Reference/KeyboardModifiers

// Controller Software for the MOD_Boy
// The MOD_Boy is Open Source Hardware that uses the HCC Module. 
// Check out the Kickstarter for the HCC Module: http://bit.ly/hccmodule
// GITHUB for all of the HCC Module stuff(and demo boards like this one): https://github.com/IdleHandsProject/samd_hcc_mod

//  USING THE MOD_BOY AS A GAME CONTROLLER -
// TIGHTLY BASED ON THE ADAFRUIT CODE FOUND HERE: https://github.com/adafruit/Adafruit_Learning_System_Guides/tree/master/Joy_game_controller
// ALL DISPLAY CODE REMOVED




struct { // Button structure:
  int8_t   pin; // Button is wired between this pin and GND
  uint8_t  key; // Corresponding key code to send
  bool     prevState;
  uint32_t lastChangeTime;
} button[] = {
  { 3, KEY_RIGHT_ARROW },              // A
  { 18, KEY_DOWN_ARROW},               // B
  { 5, KEY_LEFT_ARROW },              // Y
  { 4, KEY_UP_ARROW },              // X
  { 6, KEY_RETURN },       // Joystick select click
  { 17, KEY_ESC}
};
#define N_BUTTONS (sizeof(button) / sizeof(button[0]))
#define DEBOUNCE_US 400 // Button debounce time, microseconds

struct { // Joystick axis structure (2 axes per stick):
  int8_t  pin;   // Analog pin where stick axis is connected
  int     lower; // Typical value in left/upper position
  int     upper; // Typical value in right/lower positionax

  uint8_t key1;  // Key code to send when left/up
  uint8_t key2;  // Key code to send when down/right
  int     value; // Last-read-and-mapped value (0-1023)
  int8_t  state;
} axis[] = {
  { 16,   65, 1023, 'd', 'a' }, // X axis
  { 15, 1023,   65, 'w'  , 's' }, // Y axis
};
#define N_AXES (sizeof(axis) / sizeof(axis[0]))

uint8_t     state = 0;



// SETUP - RUNS ONCE AT STARTUP --------------------------------------------

void setup() {
  uint8_t i;


  Keyboard.begin();

  // Initialize button states...
  for (i = 0; i < N_BUTTONS; i++) {
    pinMode(button[i].pin, INPUT_PULLUP);
    button[i].prevState      = digitalRead(button[i].pin);
    button[i].lastChangeTime = micros();
  }

  // Initialize joystick state...
  for (i = 0; i < N_AXES; i++) {
    int value = map(analogRead(axis[i].pin), axis[i].lower, axis[i].upper, 0, 1023);
    if (value > (1023 * 4 / 5)) {
      Keyboard.press(axis[i].key2);
      axis[i].state =  1;
    } else if (value < (1023 / 5)) {
      Keyboard.press(axis[i].key1);
      axis[i].state = -1;
    } else {
      axis[i].state = 0;
    }
  }
}


// MAIN LOOP - RUNS OVER AND OVER FOREVER ----------------------------------

void loop() {
  uint32_t  t;
  bool      s;
  int       i, value, dx, dy;
  float     a;
  uint16_t *buf;

  // Read and debounce button inputs...
  for (i = 0; i < N_BUTTONS; i++) {
    s = digitalRead(button[i].pin);       // Current button state
    if (s != button[i].prevState) {       // Changed from before?
      t = micros();                       // Check time; wait for debounce
      if ((t - button[i].lastChangeTime) >= DEBOUNCE_US) {
        if (s) Keyboard.release(button[i].key); // Button released
        else  Keyboard.press(   button[i].key); // Button pressed
        button[i].prevState      = s; // Save new button state
        button[i].lastChangeTime = t;     // and time of change
      }
    }
  }  

  // Read joystick axes
  for (i = 0; i < N_AXES; i++) {
    // Remap analog reading to 0-1023 range (0=top/left, 1023=down/right)
    value = map(analogRead(axis[i].pin), axis[i].lower, axis[i].upper, 0, 1023);
    if (axis[i].state == 1) {           // Axis previously down/right?
      if (value < (1023 * 3 / 5)) {     // Moved up/left past hysteresis threshold?
        Keyboard.release(axis[i].key2); // Release corresponding key
        axis[i].state = 0;              // and set state to neutral center zone
      }
    } else if (axis[i].state == -1) {   // Else axis previously up/left?
      if (value > (1023 * 2 / 5)) {     // Moved down/right past hysteresis threshold?
        Keyboard.release(axis[i].key1); // Release corresponding key
        axis[i].state = 0;              // and set state to neutral center zone
      }
    } // This is intentionally NOT an 'else' -- state CAN change twice here!
    if (!axis[i].state) {               // Axis previously in neutral center zone?
      if (value > (1023 * 4 / 5)) {     // Moved down/right?
        Keyboard.press(axis[i].key2);   // Press corresponding key
        axis[i].state = 1;              // and set state to down/right
      } else if (value < (1023 / 5)) {  // Else axis moved up/left?
        Keyboard.press(axis[i].key1);   // Press corresponding key
        axis[i].state = -1;             // and set state to up/left
      }
    }
    axis[i].value = value; // Save for later
  }



}

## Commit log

2018-06-23 Boards ordered wth gerbs
    [fanfdd-B.Cu.gbr, fanfdd-B.Mask.gbr, fanfdd-B.SilkS.gbr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]
2018-06-23 restructure folders and rename
    [BOM.xlsx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]
2018-06-30 changes to filenames and folder system
    [BOM.xlsx, hcc_arduino.kicad_pcb, hcc_arduino.sch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]
2018-07-19 added demo boards
    [Board.dxf, HCC_PCB.CATPart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]
2018-07-19 added logos, changed regulator to ap2112
    [hccg.kicad_pcb, hccg.sch]
2018-07-19 Fixed USB Ground
    [hcc_cherry.kicad_pcb, hcc_cherry.sch]
2018-07-19 fixed battery connection on HCC_Boy
    [hcc_boy.kicad_pcb, hcc_boy.sch]
2018-07-19 fixed usb connector
    [cad_flag.kicad_pcb, cad_flag.sch]
2018-07-19 fixed hcc breakout board, added lipo charger
    [hcc_arduino.kicad_pcb, hcc_arduino.sch]
2018-07-26 updated hcc mod and modzilla board gerbs
    [CherryMX_pcb v2.step, PCB_Body.stl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]
2018-07-26 connected 3V3 to LEDs without needing jumper
    [hcc_cherry.kicad_pcb]
2018-07-30 cleaned up libs, removed libs from project files, removed unused footprints
    [Hackster_thumb.dxf, hackster_breakout.kicad_pcb, hackster_breakout.sch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]
2018-07-31 added Arduino Example Code Folder and files
2018-10-29 new VID/PID
2018-10-29 added footprints
2018-10-29 small changes
    [hcc_arduino.kicad_pcb, hccg.kicad_pcb, hccg.sch]
2018-11-13 Updated VID/PID
2018-11-14 added hardware folder and bootloader compilier
    [arduino_zero.cfg]
2018-11-14 updated hardware folder
    [arduino_zero.cfg]
